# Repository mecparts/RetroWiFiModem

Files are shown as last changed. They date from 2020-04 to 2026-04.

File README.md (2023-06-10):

# Retro WiFi modem

## An ESP8266 based RS232 \<-\> WiFi modem with Hayes AT style commands and LED indicators

### (And yes, this version makes the noises)

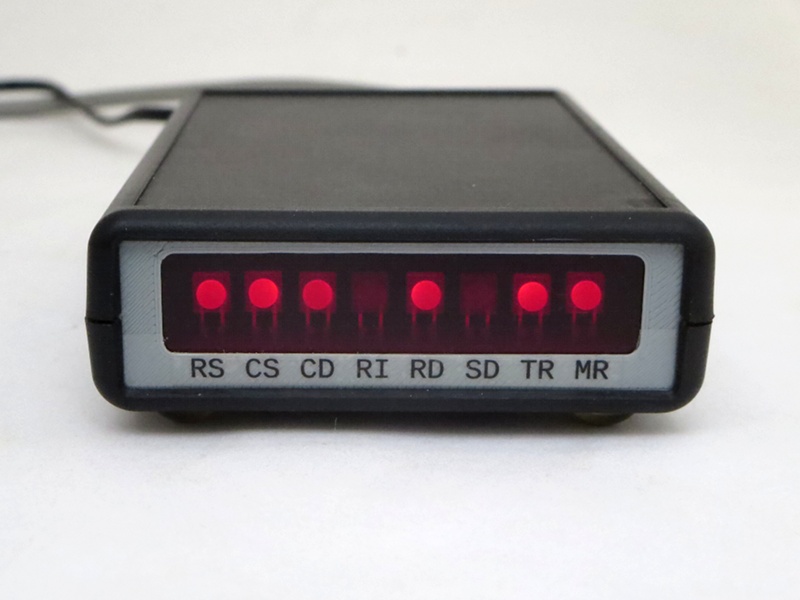
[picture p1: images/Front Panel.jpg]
Front Panel


This project grew out of a desire to get an old Ampro LB+/Z80 hooked up
to the Internet.

Right from the start, I knew I wanted a row of LED indicators at the
front of the modem so that it would be reminiscent of an old Hayes
Smartmodem. (I briefly considered finding an old Smartmodem on eBay, but
soon remembered that the case had in fact been made of metal; they don't
build 'em like that anymore.)

Since the modem was going to be hooked up to the Little Board's
serial port, I needed an actual RS-232 level serial port, with either a
DB-25 or DE-9 connector.

And finally, since I wanted the Hayes style LEDs, I thought it would be
handy to have the Hayes AT commands too, at least as close as I could
manage.

That was all I started with. I couldn't tell you how I stumbled across
the whole WiFi modem thing; I can't even remember what terms I searched
with but very quickly I came across the message thread at [WiFi232's
Evil
Clone](http://www.vcfed.org/forum/entry.php?740-WiFi232-s-Evil-Clone&bt=1056).
Inspired by that, and [Paul Rickards'
WiFi232](http://biosrhythm.com/?page_id=1453), and [Daniel Jameson's
ESP8266 based virtual modem](https://github.com/stardot/esp8266_modem) I
got started.

I had a preliminary version put together and working by the first
evening. Then the wholesale changes to the software began. And for the
longest time, it looked like they'd never end. Eventually though, they
calmed down and "wholesale changes" downshifted to "another tweak I'd
like to make."

The hardware didn't change nearly as much from beginning to end. I did
the development on a Wemos D1 R1 and a little half length solderless
breadboard mounted together. The plan for the final hardware was always
to use a [Wemos D1 mini](https://docs.wemos.cc/en/latest/d1/d1_mini.html).
A MAX3237 took care of the 3.3V <-> RS-232 level shifting, and a
74HCT245 was used to drive the indicator LEDs.

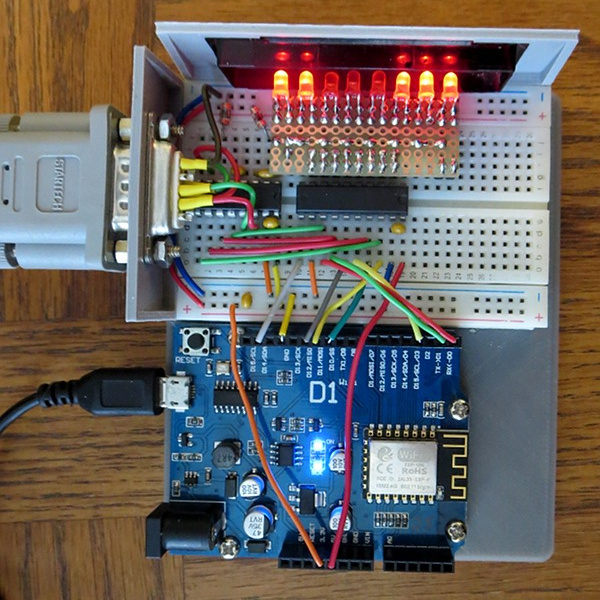
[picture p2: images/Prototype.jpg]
Prototype


The only major additions to the hardware during development was an OR
gate on the serial output from the ESP8266 and the addition of a
DFPlayer Mini for the dialing and connection sounds.

On startup, the ESP8266 sends out some debug information
(at an oddball baud rate) through the serial port. It shows up as
garbage characters to whatever's hooked up to the serial port. It
annoyed me enough that I fed the Tx signal through the OR gate, with the
other input hooked up to an output pin that I could count on remaining
high (thereby masking off the Tx signal) until after the sketch had
started and set it low.

And while it didn't make the cut the first time around, there's a
DFPlayer Mini in this version for faux dialing and connection sounds.
They really do complete the whole retro feel (but they can be turned off
too).

## The Hardware

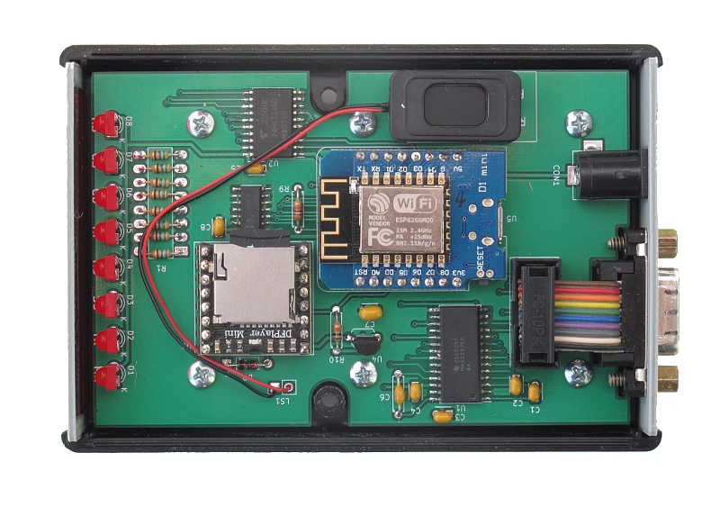
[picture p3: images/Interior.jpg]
Interior


The second time around, I decided that I was going to bite the bullet
and go with some surface mount stuff, starting with the MAX3237. Having
a full suite of RS-232 control signals seemed worth it. I stuck with
through hole components where I could (I already had most of them in my
parts box) but adding the DFPlayer Mini meant that the 74HC32 and
74HCT245 had to be surface mount just to make them fit.

In keeping with the retro theme, the modem uses classic Hayes style
blinking LEDs and a DE-9F for the RS-232 connector. Everything is
displayed and brought out to the DE-9F connector: RTS, CTS, DSR, DTR,
DCD, RI, TxD and RxD.

The PCB is laid out for a
[Wemos D1 mini](https://docs.wemos.cc/en/latest/d1/d1_mini.html) and the
software expects to see just that. If you're just using the software and
not the PCB, there's no reason you couldn't use another kind of ESP8266
board; I used a D1 R1 myself when I was developing the modem. You'd just
need to add pin definitions for your board in RetroWiFiModem.h.

A separate 3.3V regulator is used to power the MAX3232 IC and 74HC32
quad OR gate. Some (most?) D1 mini clones have the smallest 3.3V
regulator on board that they can get away with to power the board, and
they don't have a lot of mA's left over to power anything else. Better
safe than sorry.

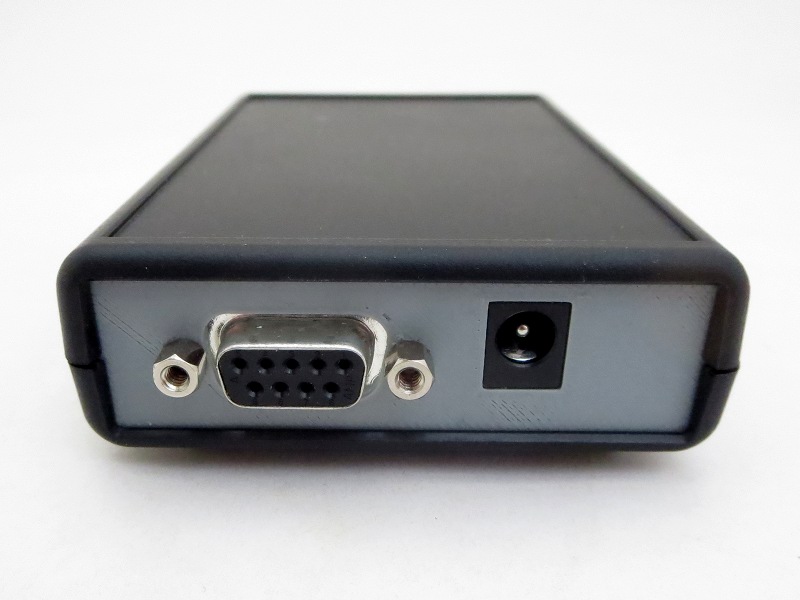
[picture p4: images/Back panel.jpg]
Back Panel


The power connector expects a 2.1mm I.D. x 5.5mm O.D. barrel plug,
delivering 5 volts, centre positive.  I used a Tri-Mag L6R06H-050 (5V,
1.2A), [DigiKey part#
364-1251-ND](https://www.digikey.com/product-detail/en/tri-mag-llc/L6R06H-050/364-1251-ND/7682614).
If you plug in a 9V adapter like you'd use for an Arduino, you *will*
let the magic smoke out and have an ex-modem on your hands.

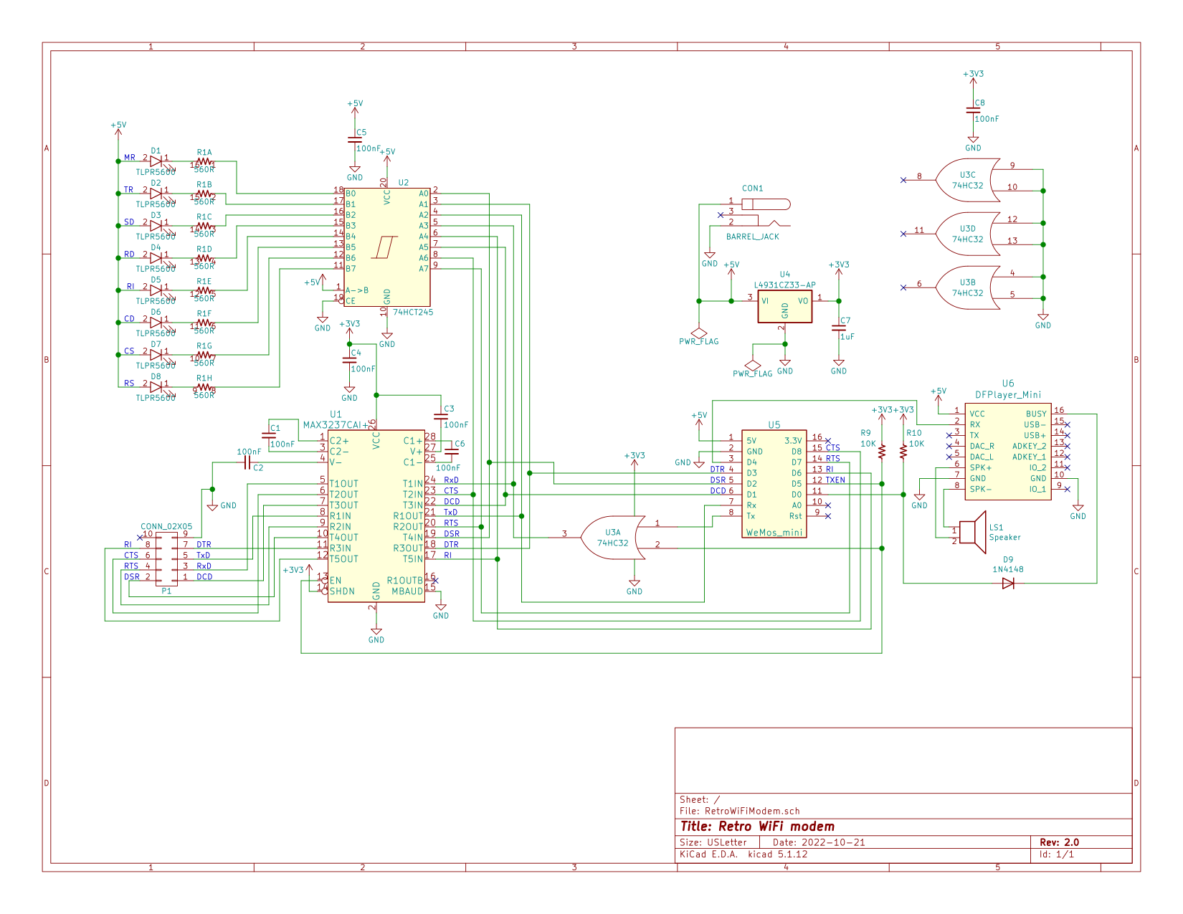
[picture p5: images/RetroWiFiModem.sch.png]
Schematic


On the off chance that there's someone else out there with a well
stocked parts box and a burning desire to put together their own WiFi
modem, there's a [BOM](kicad/RetroWiFiModem-bom.csv) in the kicad
sub directory. If you actually had to go out and buy all the parts, it
really wouldn't be cost effective.

Then again, how practical is getting an Ampro Little Board on the
Internet? Practicality isn't always everything. Sometimes nostalgia is
worth the effort.

## The case

Like I said at the start, I would have loved to have used an old Hayes
Smartmodem case, but they were metal and wouldn't have allowed the WiFi
to work particularly well.

In the end I went with a Hammond 1593N case (DigiKey part #
[HM963-ND](https://www.digikey.com/en/products/detail/hammond-manufacturing/1593NBK/1090774)
or [HM964-ND](https://www.digikey.com/en/products/detail/hammond-manufacturing/1593NGY/1090775)
depending on whether you like black or grey). STL and OpenSCAD
files are included for the front and back panels. You could use the
proper Hammond red panel for the front (DigiKey part #
[HM965-ND](https://www.digikey.com/en/products/detail/hammond-manufacturing/1593NIR10/1090776)),
*but* they're only available in 10 packs and their price is highway robbery.
I ended up using a slightly smaller red panel (DigiKey part #
[HM889-ND](https://www.digikey.com/en/products/detail/hammond-manufacturing/1593SIR10/409899))
that was ~much~ cheaper (it has recently increased in price by 500%)
and available in single units.

The labels are unbelievably low tech. I print them on a piece of inkjet
transparency film. I then cut that down to size so that it will fit
under the LED opening. Then I attach the trimmed down transparency piece
to a length of matte finish, invisible tape and carefully position it in
place. A bit of careful work with an x-acto knife and you've got
yourself a label that looks like it's part of the panel. If you look
closely at the front panel image you can see the edges of the
transparency film and the tape, but in practice they both essentially
disappear.

## The PCB

The PCB includes cutouts for the two columns that join the case
together, and mounting holes for the 6 standoffs. Also, there's an oddly
shaped cutout in back end to allow a particular IDC DE-9F I had on hand.
It's available from DigiKey (or a very close clone is) but it's fairly
pricey. But there's plenty of room for an ordinary solder cup DE-9F.
You'd most likely want to omit the 10 pin header and just wire the DE-9F
right to the board.

## The Software

In a nod to its popularity, the command set I used largely follows that
used in [Paul Rickards' WiFi232](http://biosrhythm.com/?page_id=1453)
modem. Even if the innards are completely different, it made sense to
make it *work* like what people were already used to. There's a reason
everyone's been copying the Hayes command set for almost 40 years!

### First time setup

The default serial configuration is 9600bps, 8 data bits, no parity, 1
stop bit.

Here's the commands you need to set up the modem to automatically
connect to your WiFi network:

1. `AT$SSID=your WiFi network name` to set the WiFi network that the
modem will connect to when it powers up.
2. `AT$PASS=your WiFi network password` to set the password for the
network.
3. `ATC1` to connect to the network.
4. Optional stuff:
   * `AT$SB=speed` to set the default serial speed.
   * `AT$SU=dps` to set the data bits, parity and stop bits.
   * `ATNETn` to select whether or not to use Telnet protocol.
   * `AT&Kn` to use RTS/CTS flow control or not.
   * `AT&Dn` to set up DTR handling.
5. `AT&W` to save the settings.

Once you've done that, the modem will automatically connect to your WiFi
network on power up and will be ready to "dial up" a connection with
ATDT.

### Command Reference

Multiple AT commands can be typed in on a single line. Spaces between
commands are allowed, but not within commands (i.e. AT S0=1 X1 Q0 is
fine; ATS 0=  1 is not). Commands that take a string as an argument
(e.g. AT$SSID=, AT$TTY=) assume that *everything* that follows is a part
of the string, so no commands are allowed after them.

Command | Details
------- | -------
+++     | Online escape code. Once your modem is connected to another device, the only command it recognises is an escape code of a one second pause followed by three typed plus signs and another one second pause, which puts the modem back into local command mode. The character used can be set with `ATS2=n`.
A/      | Repeats the last command entered. Do not type AT or press Enter.
AT      | The attention prefix that precedes all command except A/ and +++.
AT?     | Displays a help cheatsheet.
ATA     | Force the modem to answer an incoming connection when the conditions for auto answer have not been satisfied.
ATC?<br>ATC*n* | Query or change the current WiFi connection status. A result of 0 means that the modem is not connected to WiFi, 1 means the modem is connected. The command ATC0 disconnects the modem from a WiFi connection. ATC1 connects the modem to the WiFi.
ATDS*n* | Calls the host specified in speed dial slot *n* (0-9).
ATDT<i>[+=-]host[:port]</i> | Tries to establish a WiFi TCP connection to the specified host name or IP address. If no port number is given, 23 (Telnet) is assumed. You can also use ATDT to dial one of the speed dial slots in one of two ways:<br><br><ul><li>The alias in each speed dial slot is checked to see if it matches the specified hostname.</li><li>A host specified as 7 identical digits dials the slot indicated by the digit. (i.e. 2222222 would speed dial the host in slot 2).</li></ul>Preceding the host name or IP address with a +, = or - character overrides the ATNET setting for the period of the connection.<br><br><ul><li>**+** forces NET2 (fake Telnet)</li><li>**=** forces NET1 (real Telnet)</li><li>**-** forces NET0 (no Telnet)</li></ul>Once the dial attempt has begun, pressing any key before the connection is established will abort the attempt.
ATE?<br>ATE*n* | Command mode echo. Enables or disables the display of your typed commands.<br><br><ul><li>E0 Command mode echo OFF. Your typing will not appear on the screen.</li><li>E1 Command mode echo ON. Your typing will appear on the screen.</li></ul>
ATGET*http&#58;//host[/page]* | Displays the contents of a website page. **https** connections are not supported. Once the contents have been displayed, the connection will automatically terminate.
ATH | Hangs up (ends) the current connection.
ATI | Displays the current network status, including sketch build date, WiFi and call connection state, SSID name, IP address, and bytes transferred.
ATL?<br>ATL*n* | Query or set the volume of the speaker (0-3).
ATM?<br>ATM*n* | Query or set whether the speaker is enabled or disabled. ATM0 disables the speaker. ATM1 enables it.
ATNET?<br>ATNET*n* | Query or change whether telnet protocol is enabled. A result of 0 means that telnet protocol is disabled; 1 is *Real* telnet protocol and 2 is *Fake* telnet protocol. If you are connecting to a telnet server, it may expect the modem to respond to various telnet commands, such as terminal name (set with `AT$TTY`), terminal window size (set with `AT$TTS`) or terminal speed. Telnet protocol should be enabled for these sites, or you will at best see occasional garbage characters on your screen, or at worst the connection may fail.<br><br>The difference between *real* and *fake* telnet protocol is this: with *real* telnet protocol, a carriage return (CR) character being sent from the modem to the telnet server always has a NUL character added after it. The implementation of the telnet protocol used by some BBSes doesn't properly strip out the NUL character. When connecting to such BBSes (Particles! is one), use *fake* telnet.<br><br>When using *real* telnet protocol, when the telnet server sends a CR character followed by a NUL character, only the CR character will be sent to the serial port; the NUL character will be silently stripped out. With *fake* telnet protocol, the NUL will be passed through.
ATO | Return online. Use with the escape code (+++) to toggle between command and online modes.
ATQ?<br>ATQ*n* | Enable or disable the display of result codes. The default is Q0.<br><br><ul><li>Q0 Display result codes.</li><li>Q1 Suppress result codes (quiet).</li></ul>
ATRD<br>ATRT | Displays the current UTC date and time from NIST in the format *YY-MM-DD HH:MM:SS*. A WiFi connection is required and you cannot be connected to another site.
ATS0?<br>ATS0=*n* | Display or set the number of "rings" before answering an incoming connection. Setting `S0=0` means "don't answer".
ATS2?<br>ATS2=*n* | Display or set the ASCII code used in the online escape sequence. The default value is 43 (the + plus character). Setting it to any value between 128 and 255 will disable the online escape function.
ATV?<br>ATV*n* | Display result codes in words or numbers. The default is V1.<br><br><ul><li>V0 Display result codes in numeric form.</li><li>V1 Display result codes in text form.</li></ul>
ATX?<br>ATX*n* | Control the amount of information displayed in the result codes. The default is X1 (extended codes).<br><br><ul><li>X0 Display basic codes (CONNECT, NO CARRIER)</li><li>X1 Display extended codes (CONNECT speed, NO CARRIER (connect time))</li></ul>
ATZ | Resets the modem.
AT&F | Reset the NVRAM contents and current settings to the sketch defaults. All settings, including SSID name, password and speed dial slots are affected.
AT&D?<br>AT&D*n* | Display or set the handling of DTR going inactive. The default is &D0 (ignored).<br><br><ul><li>&D0 Ignore</li><li>&D1 Go to command mode</li><li>&D2 End call</li><li>&D3 Reset modem</li></ul>
AT&K?<br>AT&K*n* | Data flow control. Prevents the modem's buffers for received and transmitted from overflowing.<br><br><ul><li>&K0 Disable data flow control.</li><li>&K1 Use hardware flow control. Requires that your computer and software support Clear to Send (CTS) and Request to Send (RTS) at the RS-232 interface.</li></ul>
AT&R?<br>AT&R=*server pwd* | Query or change the password for incoming connections. If set, the user has 3 chances in 60 seconds to enter the correct password or the modem will end the connection.
AT&V*n* | Display current or stored settings.<br><br><ul><li>&V0 Display current settings.</li><li>&V1 Display stored settings.</li></ul>
AT&W | Save current settings to NVRAM.
AT&Zn?<br>AT&Z*n*=*host[:port],alias* | Store up to 10 numbers in NVRAM, where *n* is the position 0-9 in NVRAM, and *host[:port]* is the host string, and *alias* is the speed dial alias name. The host string may be up to 50 characters long, and the alias string may be up to 16 characters long.<br><br>Example: `AT&Z2=particlesbbs.dyndns.org:6400,particles`<br><br>This number can then be dialed in any of the following ways:<br><br><ul><li>`ATDS2`</li><li>`ATDTparticles`</li><li>`ATDT2222222`</li></ul>
AT$AE?<br>AT$AE=*startup AT cmd* | Query or change the command line to be executed when the modem starts up.
AT$AYT | Sends a Telnet "Are You There?" command if connected to a Telnet remote.
AT$BM?<br>AT$BM=*server busy msg* | Query or change a message to be returned to an incoming connection if the modem is busy (i.e. already has a connection established).
AT$MDNS<br>AT$MDNS=*mDNS name* | Query or change the mDNS network name (defaults to "espmodem"). When a non zero TCP port is defined, you can telnet to that port with **telnet mdnsname.local port**.
AT$PASS?<br>AT$PASS=*WiFi pwd* | Query or change the current WiFi password. The password is case sensitive. Clear the password by issuing the set command with no password. The maximum length of the password is 64 characters.
AT$SB?<br>AT$SB=*n* | Query or change the current baud rate. Valid values for "n" are 110, 300, 450, 600, 710, 1200, 2400, 4800, 9600, 19200, 38400, 57600, 76800 and 115200. Any other value will return an ERROR message. The default baud rate is 1200. The Retro WiFi modem does not automatically detect baud rate like a dial-up modem. The baud rate setting must match that of your terminal to operate properly. It will display garbage in your terminal otherwise.
AT$SP?<br>AT$SP=*n* | TCP server port to listen on. A value of 0 means that the TCP server is disabled, and no incoming connections are allowed.
AT$SSID?<br>AT$SSID=*ssid name* | Query or change the current SSID to the specified name. The given SSID name is case sensitive. Clear the SSID by issuing the set command with no SSID. The maximum length of the SSID name is 32 characters.
AT$SU?<br>AT$SU=*dps* | Query or change the current number of data bits ('d'), parity ('p') and stop bits ('s") of the serial UART. Valid values for 'd' are 5, 6, 7 or 8 bits. Valid values for 'p' are (N)one, (O)dd or (E)ven parity. Valid values for 's' are 1 or 2 bits. The default settings are 8N1. The UART setting must match your terminal to work properly.
AT$TTL?<br>AT$TTL=*telnet location* | Query or change the Telnet location value to be returned when the Telnet server issues a SEND-LOCATION request. The default value is "Computer Room".
AT$TTS?<br>AT$TTS=*WxH* | Query or change the window size (columns x rows) to be returned when the Telnet server issues a NAWS (Negotiate About Window Size) request. The default value is 80x24. For terminals that are smaller than 80x24, setting these values appropriately will enable paging on the help (AT?) and network status (ATI) commands.
AT$TTY?<br>AT$TTY=*terminal type* | Query or change the terminal type to be returned when the Telnet server issues a TERMINAL-TYPE request. The default value is "ansi".
AT$W?<br>AT$W=*n* | Startup wait.<br><br><ul><li>$W=0 Startup with no wait.</li><li>$W=1 Wait for the return key to be pressed at startup.</li></ul>

### Updating the Software

While I liked the idea of being able to update the software OTA, it
seemed to make more sense in my situation to be able to *push* a new
version as I built it rather than have the modem *pull* it. So that's
what I did. It uses the default OTA upload capability built into the
Arduino IDE.

**Jan 24/22:** It's been reported that the ESP8266 core is slightly
snafu'd at the moment, and that it's breaking things in the modem
software. As a workaround, I've added the bin file that gets uploaded
to the modem in the repository. I haven't updated my ESP8266 core in
ages; "if it isn't broken, don't break it", and everything still works
for me. The bin file can be uploaded with the *espota.py* tool in the
ESP8266 tool directory tree.

(If TPTB have deleted/renamed/moved that tool in the current core,
you'll have to figure out how to do a manual OTA update.)

### RTS/CTS handshaking and a dead spin loop issue

Something I noticed with ESP8266 software that puzzled me was the
number of places I saw a series of Serial print statements being broken
up with calls to yield(), like so:

```
   Serial.print("Hello world!\n");
   yield();
   Serial.print("How are you today?\n");
   yield();
```
It didn't take long to figure out what was going on; The print() call
was blocking, and at lower baud rates, even printing a few relatively
short strings was enough to cause the watchdog to bark and cause a
reset. So the repetitive yield() calls were an attempt to feed the
watchdog often enough to keep it from barking.

What does this have to do with RTS/CTS handshaking? Simply put,
lowering RTS for more than a few seconds was causing the watchdog to
bark as well. So I started digging.

In cores/esp8266/uart.cpp I found the following function:

```
static void
uart_do_write_char(const int uart_nr, char c)
{
    while(uart_tx_fifo_full(uart_nr));

    USF(uart_nr) = c;
}
```

This is the low level function that everything calls to send a character
out the serial port. The cause of the watchdog barking is in the dead
spin while loop. It waits until there's room in the transmit FIFO to add
another character. So if RTS/CTS handshaking is enabled, and RTS is low
for longer than the watchdog likes: woof.

What I did to quiet the watchdog down both when sending long strings at
low baud rates and during long waits for RTS to come active again was to
add a yield() call to the dead spin while loop, like so:

```
static void
uart_do_write_char(const int uart_nr, char c)
{
    while(uart_tx_fifo_full(uart_nr))
      yield();

    USF(uart_nr) = c;
}
```

This way, no matter how long the code has to wait for space in the
transmit FIFO, the watchdog is kept well fed and quiet.

## Status

As I said way back in 2020, is a personal project like this ever
*really* finished? I've had two units assembled and in use since the
spring of 2020, and a third since 2022, and while there's
been some software changes since then, and a second rev of the hardware
to bring out all the RS-232 control signals and add in the faux dialing
and connections sounds, I really don't expect any more changes. But I've
said that before! There are no outstanding bugs that I'm aware of, and
no new features on my wish list. For the time being at least, I think
it's complete.

### Linux, Telnet, Zmodem and downloading binary files

Have you used the modem to 'dial' into a Linux box? And have you done a
`sz binary_file` on the Linux box? And at a completely reproducible
point in the file, has the connection dropped? But other binary files
work just fine? Then read on.

This drove me slightly batty for months. I finally narrowed it down to
trying to send blocks of binary data with a large number of FF bytes. I
eventually created a test file consisting of 2K of FF and used that to
test with. I could download it through the modem with Xmodem just fine.
Ymodem also worked if I kept the block size down to 128 bytes - but the
connection would drop instantly if I tried sending 1K blocks. Same thing
with Zmodem.

In fact, if I just tried `cat binary_file`, the connection would
drop. Which eventually got me thinking. Sitting at the console on my
main Linux box, I telnet'd to the same box and logged in. No WiFi modem
involved anywhere, just a telnet session on the console to the same box.
I then did a `cat binary_file`. The telnet connection dropped, and I
was back in my original session.

It's the Linux telnet daemon. Not the modem at all.

To prove it to myself, I hooked up WiFi modems to two systems on their
serial ports and had one dial into the other. I could send the all FF
binary file back and forth with Zmodem and Ymodem, no trouble at all.

But you really, really need to download that binary file through the
modem from a telnet connection to a Linux box? You're not going to be
able to use Zmodem. Ymodem will work (the sy command defaults to 128
byte blocks), as will Xmodem. But not Zmodem.

Oddly enough, the telnet daemon has no trouble *receiving* the all FF
binary file. Only sending it. Your guess as to why is probably better
than mine.

## References

* [WiFi232 - An Internet Hayes Modem for your Retro Computer](http://biosrhythm.com/?page_id=1453)<br>
* [WiFi232's Evil Clone](https://forum.vcfed.org/index.php?threads/wifi232s-evil-clone.1070412/)<br>
* [Jussi Salin's Virtual modem for ESP8266](https://github.com/jsalin/esp8266_modem)<br>
* [Stardot's ESP8266 based virtual modem](https://github.com/stardot/esp8266_modem)<br>
* [Roland Juno's ESP8266 based virtual modem](https://github.com/RolandJuno/esp8266_modem)

## Acknowledgements

* A whole lot of people owe a big vote of thanks to Jussi Salin for
releasing their virtual modem code for the ESP8266 and starting the
ball rolling.
* Paul Rickards for an amazing bit of hardware to draw inspiration from.
* All the Stardot contributors for their work.
* And, of course, Dennis C. Hayes for creating something so simple and
elegant that has stood the test of time.

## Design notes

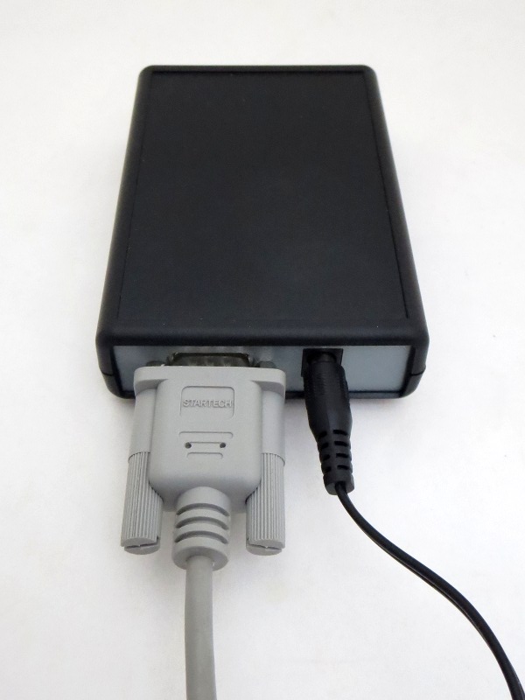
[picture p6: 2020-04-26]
images/Plugged in.jpg

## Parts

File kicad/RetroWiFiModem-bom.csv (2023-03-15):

Reference | Quantity | Value | DigiKey PN | BC-Robotics PN
P1 | 1 | CONN_02X05 | ED1543-ND
U3 | 1 | SN74HC32DR | 296-1199-1-ND
U4 | 1 | L4931CZ33-AP | LP2950ACZ-3.3GOS-ND
D3-D8 | 8 | TLPR5600 | TLPR5600-ND
C1-C2,C4-C6,C8 | 6 | 100nF | 399-9859-1-ND
C7 | 1 | 1uF | 399-3529-ND
CON1 | 1 | BARREL_JACK | 839-54-00166-ND
R1 | 8 | 560R | CF18JT560RCT-ND
R9-R10 | 2 | 10K | CF18JT10K0CT-ND
U1 | 1 | MAX3237ECDWR | 296-36945-1-ND
U2 | 1 | 74HCT245D | 74HCT245DCT-ND
C3 | 1 | 100nF | 399-9859-1-ND
U5 | 1 | WeMos_mini
U6 | 1 | DFPlayer_Mini | 1738-1041-ND
LS1 | 1 | Speaker |  | AUD-013
D9 | 1 | 1N4148 | 1N4148FS-ND
 | 1 | Hammond 1593NBK case | HM963-ND
 | 1 | Hammond red panel | HM889-ND
 | 50 | PCB screws | HM1442-ND
 | 1 | 5V wall adapter | 364-1251-ND
 | 1 | DE-9F IDC connector | 5746861-4-ND
 | 2 | 4-40 hex standoffs | A104867-ND
 | 4 | 8 pos machine pin socket | 2057-SMC-1-08-1-GT-ND
 | 1 | 10 pos IDC socket | 1175-1443-ND
 | 1 | 10 cond ribbon cable | 3M157815-1-ND

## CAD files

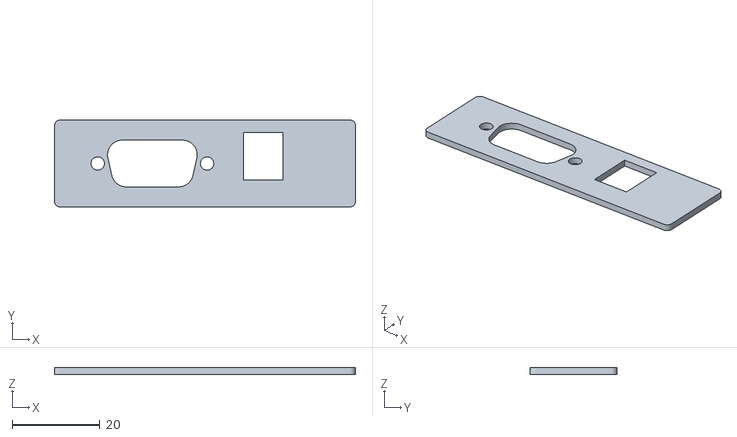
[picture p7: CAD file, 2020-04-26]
case/back_panel.stl
68.8 x 19.8 x 1.50

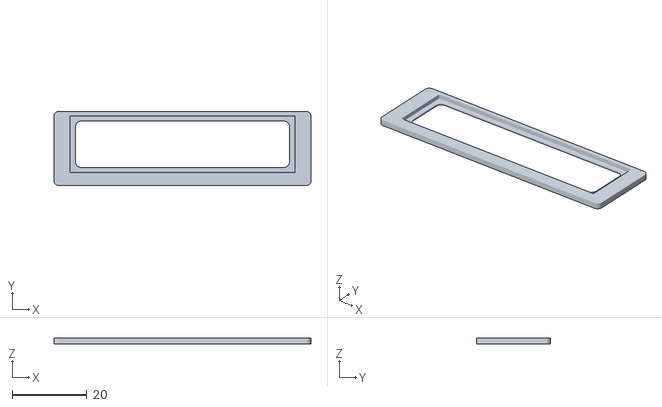
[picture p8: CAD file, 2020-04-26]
case/front_panel.stl
68.8 x 19.8 x 1.50

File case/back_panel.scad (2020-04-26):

$fn=64;
eps = 0.04;
inch = 25.4;

panel_x = 68.76;
panel_y = 19.84;
panel_z = 1.5;
panel_r = 0.05 * inch;

barrel_x = 0.354*inch;
barrel_y = 0.428*inch;

module dsub(c,e,a)
{
   r=3.35;
   h=3.96;
   md=3.05;
   hull() {
      translate([-c/2,h/2,0])
         circle(r=r);
      translate([c/2,h/2,0])
         circle(r=r);
      translate([-e/2,-h/2,0])
         circle(r=r);
      translate([e/2,-h/2,0])
         circle(r=r);
   }
   translate([-a/2,0,0])
      circle(d=md);
   translate([a/2,0,0])
      circle(d=md);
}

module dsub9() {
   dsub(c=13.77,e=12.01,a=24.99);
}

difference() {
   linear_extrude(height=panel_z) {
      hull() {
         translate([panel_r, panel_r, 0]) {
            circle(r=panel_r);
         }
         translate([panel_x-panel_r, panel_r, 0]) {
            circle(r=panel_r);
         }
         translate([panel_x-panel_r, panel_y-panel_r, 0]) {
            circle(r=panel_r);
         }
         translate([panel_r, panel_y-panel_r, 0]) {
            circle(r=panel_r);
         }
      }
   }
   translate([panel_x/2 - 12.015, panel_y/2, -eps] ) {
      linear_extrude(height=panel_z+2*eps) {
         dsub9();
      }
   }
   translate([panel_x/2+13.33,6.17+barrel_y/2,-eps]) {
      linear_extrude(height=panel_z+2*eps) {
         square([barrel_x, barrel_y],center=true);
      }
   }
}

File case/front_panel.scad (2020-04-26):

$fn=64;
eps = 0.04;
inch = 25.4;

panel_x = 68.76;
panel_y = 19.84;
panel_z = 1.5;
panel_r = 0.05 * inch;

lens_x = 2.363 * inch;
lens_y = 0.592 * inch;
lens_z = 0.062 * inch;

bezel_x = 2.258 * inch;
bezel_y = 0.487 * inch;
bezel_r = 1/16 * inch;

difference() {
   linear_extrude(height=panel_z) {
      hull() {
         translate([panel_r, panel_r, 0]) {
            circle(r=panel_r);
         }
         translate([panel_x-panel_r, panel_r, 0]) {
            circle(r=panel_r);
         }
         translate([panel_x-panel_r, panel_y-panel_r, 0]) {
            circle(r=panel_r);
         }
         translate([panel_r, panel_y-panel_r, 0]) {
            circle(r=panel_r);
         }
      }
   }
   translate([panel_x/2,panel_y-1.27-lens_y/2,0.4]) {
      linear_extrude(height=panel_z+2*eps) {
         square([lens_x+2*eps, lens_y+2*eps],center=true);
      }
   }
   translate([panel_x/2,panel_y-1.27-lens_y/2,-eps]) {
      linear_extrude(height=panel_z+2*eps) {
         hull() {
            translate([-bezel_x/2+bezel_r, -bezel_y/2+bezel_r, 0]) {
               circle(r=bezel_r);
            }
            translate([bezel_x/2-bezel_r, -bezel_y/2+bezel_r, 0]) {
               circle(r=bezel_r);
            }
            translate([bezel_x/2-bezel_r, bezel_y/2-bezel_r, 0]) {
               circle(r=bezel_r);
            }
            translate([-bezel_x/2+bezel_r, bezel_y/2-bezel_r, 0]) {
               circle(r=bezel_r);
            }
         }
      }
   }
}

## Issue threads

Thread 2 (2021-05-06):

use with ESP 12e module.

Biker1bob, 2021-05-06:
Wanted to ask, but I cannot find any way to contact you. I could use your firmware with an ESP 12e module by making sure the pin out is correct?
When I try and use your code in Adruino IDE it says there is a missing ESP_EEPROM.h .. now I have done this with a FLASHER and .bin but not with the IDE .. is that something it finds once I choose the board?
Sorry for using the issues page.. but could not contact you otherwise.

mecparts, 2021-05-06:
I can't think of any reason off the top of my head why you couldn't make a bare ESP12e module work with the firmware.

As for the missing ESP_EEPROM.h... did you install the library?

Biker1bob, 2021-05-06:
NodeMCU V3 Lua ESP8266 is the exact module, so I have the pinouts right there. I have programmed Zimodem. but its setup for a C64.. you have made specific changes for RS232. I would like to try and run the LEDs off the signal pins - to a resistor and then to LEDS in a old plastic modem case I have. Should work I think.

Biker1bob, 2021-05-06:
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

mecparts, 2021-05-06:
A NodeMCU board? I don't imagine you'll have many problems with that. Just check how the pins are mapped and add the mappings to RetroWifiModem.h. It wouldn't surprise me if they're exactly the same as the D1 Mini; the original D1 was the odd duck as I recall.

Biker1bob, 2021-05-06:
Do I need to change the name in the file  #include NodeMCU?  In order to compile and test do I need the board plugged in?

Not getting far with Arduno IDE

James

mecparts, 2021-05-07:
No, as it says in the readme, and as I said in an earlier message, all you should have to do is to add the correct pin mapping for your board in the RetroWifiModem.h file.

Biker1bob, 2021-05-07:
guess I am not getting it.. I dont know how to get it to accept the .h files it cannot find.

mecparts, 2021-05-07:
Your issues seem to be with the IDE rather than the firmware, but... I imagine you haven't installed the libraries you need. If this is your first time using the Arduino IDE, perhaps you'd do better starting with a simpler example to get your feet wet, and then working your way up.

Biker1bob, 2021-05-07:
Thanks for your project I'll see what I can figure out.

DRF-Solutions, 2021-06-17:
@Biker1bob Did you manage to get this working? I too am using the same board as you and ran into the same issue.
I managed to get libraries installed, and now get errors at compile stating the below.
I did also try changing the #ifdef ARDUINO_ESP8266_NODEMCU, to no avail...

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

DRF-Solutions, 2021-06-18:
I think the issue is a certain library has been used, but the exact library used hasn't been mentioned or documented anywhere - making this project useless to anyone who doesn't already have that library installed.

@mecparts, can you please advise which libraries you have installed that are supporting this project?

Thanks

mecparts, 2021-06-18:
I would have thought that the #includes <...> in the main sketch file would have made the libraries used pretty clear. And the only library used that isn't included with the standard ESP8266 install is ESP_EEPROM. Which has nothing to do with defining the I/O pins, by the way. As stated in the README file:

> If you're just using the software and not the PCB, there's no reason you couldn't use another kind of ESP8266 board; I used a D1 R1 myself when I was developing the modem. You'd just need to **add pin definitions for your board in RetroWiFiModem.h**.

Biker1bob, 2021-06-18:
> @Biker1bob Did you manage to get this working? I too am using the same board as you and ran into the same issue.

No I have no luck using Arduino IDE or other programmers. I was able to get zimodem in a .bin which uploaded fine. I have been using my esp8266 wimodem for a month now.

Good luck.

Closed 2021-05-07.

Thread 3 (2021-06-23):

Question about PCB and front panel labels

sofakng, 2021-06-23:
This is a fantastic project and I absolutely love the design!

Do you have the gerber files so I can order a PCB?

Also, how did you make the front panel piece with the signal labels?

mecparts, 2021-06-24:
I'm glad to hear you like my little pandemic project. I've built (and use daily) two of them and am even thinking of putting together a third for another retro computer I'm bringing back to life.

As a pandemic project (i.e. "build it on the cheap with what I have on hand as much as possible") I went low tech on the PCB construction, so I never made Gerber files. Printed off the design on a sheet of that blue 'Press-n-Peel' transfer film, ironed it onto some copper clad board, etched it in an ammonium persulfate solution out on the deck on a hot summer day, drilled and trimmed it. As I said, low tech. But all done with stuff that I had from projects long ago.

Though... I see there's a place offering free PCBs up to 100mm x 150mm now. Maybe I should think about making some Gerbers and getting some boards made. I'd know then if the Gerbers were actually right and could put them up. It's worth looking into (I have visions of the "free" PCBs coming with a 50 buck customs clearing charge from the courier!).

If you look closely at the front panel picture, you can see a change in texture on the 3D printed panel just below the midline of the case. That's a piece of scotch tape, which is holding a piece of transparency film. I picked a font that looked good to me, used a table to get the spacing even, printed the letters on the film, cut it down to size and taped it on. Once again, low tech, cheap, but it works!

sofakng, 2021-06-25:
Thanks so much for the reply!  I've actually purchased a used Hayes 1200 modem to use for this project but then I also forgot about the metal body and wireless signal.

What is the place offering free PCBs?  I've ordered from JLCPCB and it's extremely cheap, but the shipping is expensive.

If you decide to create some gerbers I'd love to give them a try and thanks again for all the information!

mecparts, 2021-06-27:
It's called ALLPCB. I've only taken the briefest of looks at it; I've just got too many balls in the air right now. If it does turn out that it's really free I know I won't be able to stop myself from sitting down, figuring out the gerbers and getting some boards made to check if I've done them right.

sofakng, 2021-06-28:
That's really interesting.  It sells one coupon per month per user for the free PCB and free shipping.

One last question ... what is the purpose of the 74HCT245 and 74HC32 chips?  I see they connect to the LEDs?

mecparts, 2021-06-28:
The side facing LEDs are older items and need a fair bit more current than today's LEDs. The 245 was put in to supply that current w/o overtaxing the 8266s outputs (and why a 245 transceiver rather than say a 244 buffer? I had them on hand). As for the 32 quad OR gate, I'll just let the README speak for itself:

> The only major addition to the hardware during development was an OR gate on the serial output from the ESP8266. On startup, the ESP8266 sends out some debug information (at an oddball baud rate) through the serial port. It shows up as garbage characters to whatever's hooked up to the serial port. It annoyed me enough that I fed the Tx signal through the OR gate, with the other input hooked up to an output pin that I could count on remaining high (thereby masking off the Tx signal) until after the sketch had started and set it low.

sofakng, 2021-07-02:
Thanks again so much for the help!

Closed 2021-07-02.

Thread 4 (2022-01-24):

AT$AE no longer works & mDNS not broadcasting

SanguineBrah, 2022-01-24:
First, thanks for publishing this project. I had a ton of fun putting it together.

I have three modems built - the first was flashed in May of 2021 and the other two in August. It seems that the two more recent modems are showing issues that the earlier one does not:

- The auto exec function seems to be broken. No matter what it is set to, the modem always returns ERROR on power on/ATZ.
- They connect to wifi okay, can be pinged by using their IP address, however they do not broadcast on mDNS and do not show up in the Arduino IDE. I have confirmed this using Bonjour Browser, which shows several broadcasts from my media server but nothing from the modem. The modem from May shows up as it should however.

I've also desoldered and reflashed one of the newer modems with a build that was compiled today and can confirm that both issues are still showing.

Since the code hasn't really changed very much, I feel like this must be a problem with the libraries.

mecparts, 2022-01-24:
A cursory look at open issues in the ESP8266 core reveals that TPTB apparently [broke something in mDNS](https://github.com/esp8266/Arduino/issues/8344) last year and that they're going to look at it in their next sprint - whenever that is. The ESP8266 core being slightly snafu'd isn't something I can do much about. I haven't updated my core in ages, on the "if it isn't broken, don't break it" principle. AT$AE still works fine for me, as does mDNS as you can see below.

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

All I can think of to do from my end is to add the bin file that gets uploaded to the repository. You'll have to work out on your own how to manually upload that; in my ancient core there's a Python program called *espota.py* in the esp8266/tools directory tree that does the job. I make no assumptions that they haven't deleted/renamed/moved it in the current core.

SanguineBrah, 2022-01-24:
Thanks, a working bin will at least get me up and running again until the issue is resolved. Unfortunately, I tried espota.py already following advice in [this thread](https://forum.arduino.cc/t/ota_mode-no-network-port-is-shown/552931/42) and didn't have much luck but I have a desoldering station so it won't be too traumatising to pull the module again and reflash by usb.

SanguineBrah, 2022-01-24:
I can confirm that rolling back to ESP8266 core 2.7.4 and compiling again fixes both of the issues listed above.

mecparts, 2022-01-25:
That's excellent news. It's not excellent that the core is slightly borked, but you know what I mean. I'll close this one out now.

Closed 2022-01-25.

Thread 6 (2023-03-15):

Prevent Telnet server from attempting to enable (unsupported) compression

benryves, 2023-03-15:
I've been having a lot of fun with this project, so thank you for putting it together!

One issue I encountered was a large amount of binary data being dumped to the console when connecting to the [Discworld MUD](http://discworld.imaginary.com/lpc/index.html), i.e. after `atdt discworld.imaginary.com`.

It looks like the MUD attempts to enable [the `COMPRESS2` option](https://www.gammon.com.au/mccp/protocol.html) which the default implementation accepts but doesn't support, hence the garbled binary content instead of the plain text.

I've attached a patch which explicitly blocks attempts to use the `COMPRESS` or `COMPRESS2` options: [dont-compress.patch](https://github.com/mecparts/RetroWiFiModem/files/10985160/dont-compress.patch)

There are still issues connecting to this particular MUD but at least blocking the compression options means you have a better chance of reading what's going on. Thank you again!

mecparts, 2023-03-16:
You can probably imagine my confusion upon first reading... COMPRESS2? I don't recognise that Telnet option... oh, it's a MUD _extension_ to Telnet!

I tried replying DONT to COMPRESS, COMPRESS2 and COMPRESS3 and it's better but still not great. There's still a great glob of text that appears after the first "Your choice: " prompt.

I turned on Telnet option display and there's about another handful of extension options that the server is sending. Replying DONT to all of those got rid of the glob of text but there's still one more gotcha. The server seems to want the client end to be in LINEMODE. That's quite literally a first for anything I've connected to (which, admittedly, consists mostly of Telnet BBSes and actual Linux Telnet servers). So there's no support whatsoever for LINEMODE in the code. Zero. And the server doesn't appear to take DONT for an answer either, at least at first blush. So there's no echo of what you type, which I could see being a problem.

Let me ponder this for a bit and see if I can't figure out how to get the server to work in DONT LINEMODE mode.

benryves, 2023-03-16:
Thank you and sorry to open this particular can of worms, in that case!

The `LINEMODE` issue is one I'd been pondering too. If local echo was sufficient then there is the [VT102](https://vt100.net/docs/vt102-ug/chapter5.html#S5.5.2.13)/[ANSI](https://mdfs.net/Docs/Comp/Comms/ANSICodes) sequence `"\x1B[12l"` to enable local echo and `"\x1B[12h"` to disable it which may be an option if `AT$TTY` was set appropriately (rather than attempting to spoof it in the modem code).

mecparts, 2023-03-20:
Yeah... it's a can of worms all right.
Your MUD server ignored everything I threw at it to get it to go into character mode. Literally ignored. It didn't even reply with DONTs.
I've pushed a commit to DONT all the MUD server's telopt requests. But as for linemode, feel free to fork the code and have at it for yourself. It's just such a niche case that it's not worth pursuing it any further for me.

Closed 2023-03-20.

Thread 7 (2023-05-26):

Difference in v1 and v2 of the project?

sofakng, 2023-05-26:
This project looks absolutely fantastic!

I'm thinking about ordering a PCB and building one but I noticed you have an initial commit for a new version(?).

Has the PCB changed between the versions?  (do you have an extra PCB I can buy from you if you live in the US?)

Thanks!

mecparts, 2023-05-26:
v2 went with surface mount ICs, changed from a MAX3232 to a 3237 to get the full suite of RS232 signals, and added the DFPlayer module. So, yes, the v2 PCB is different than the v1. I only ever made a couple of v1 boards, and those were by hand (iron on toner, ammonium persulfate etchant, drill with a Dremel, the whole 80s experience).

Unfortunately, I'm on the other side of the 49th parallel from the US. Believe it or not, it'd be cheaper ordering your own set of boards from JLCPCB (<$10 Cdn if you choose the cheap shipping, and it's still very quick to arrive) than it would be to try mailing one from Canada to the US.

sofakng, 2023-05-26:
Oh, OK - No problem!

Is the BOM current from the kicad folder?

mecparts, 2023-05-26:
It ought to be. There were no part changes between when it was generated and the gerbers were made, only a footprint adjustment on the DFplayer (I didn't double check a 3rd party footprint and of course it bit me!).

sofakng, 2023-05-26:
Sounds good.  Thanks for such a great project!

mecparts, 2023-05-26:
Enjoy!

Closed 2023-05-26.

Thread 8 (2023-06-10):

How did you print the carrier signals on the front panel?

sofakng, 2023-06-10:
Thanks for such a great project!  I've ordered the PCB and I'm about to order the parts but I have a question.

How did you print the carrier signal labels (RS, CS, CD, etc) on the gray piece?

Also, if you live in the USA, do you have a single piece of that red screen I could purchase?  Digikey and Mouser are sold out.  :(

mecparts, 2023-06-10:
The labels are unbelievably low tech. I print them on a piece of inkjet transparency film. I then cut that down to size so that it will fit under the LED opening. Then I attach the trimmed down transparency piece to a length of matte finish, invisible tape and carefully position it in place. A bit of careful work with an x-acto knife and you've got yourself a label that looks like it's part of the panel. If you look closely at the front panel image you can see the edges of the transparency film and the tape, but in practice they both essentially disappear.

I really ought to add that to the readme.

The red filter is out of stock? Yes, I see that it is. And I see that its price has increased by 500%. Ouch! Unfortunately I'm not in the US. DigiKey claims they'll be back in stock in a week; if they're accurate, that's probably your best bet.

Closed 2023-06-11.

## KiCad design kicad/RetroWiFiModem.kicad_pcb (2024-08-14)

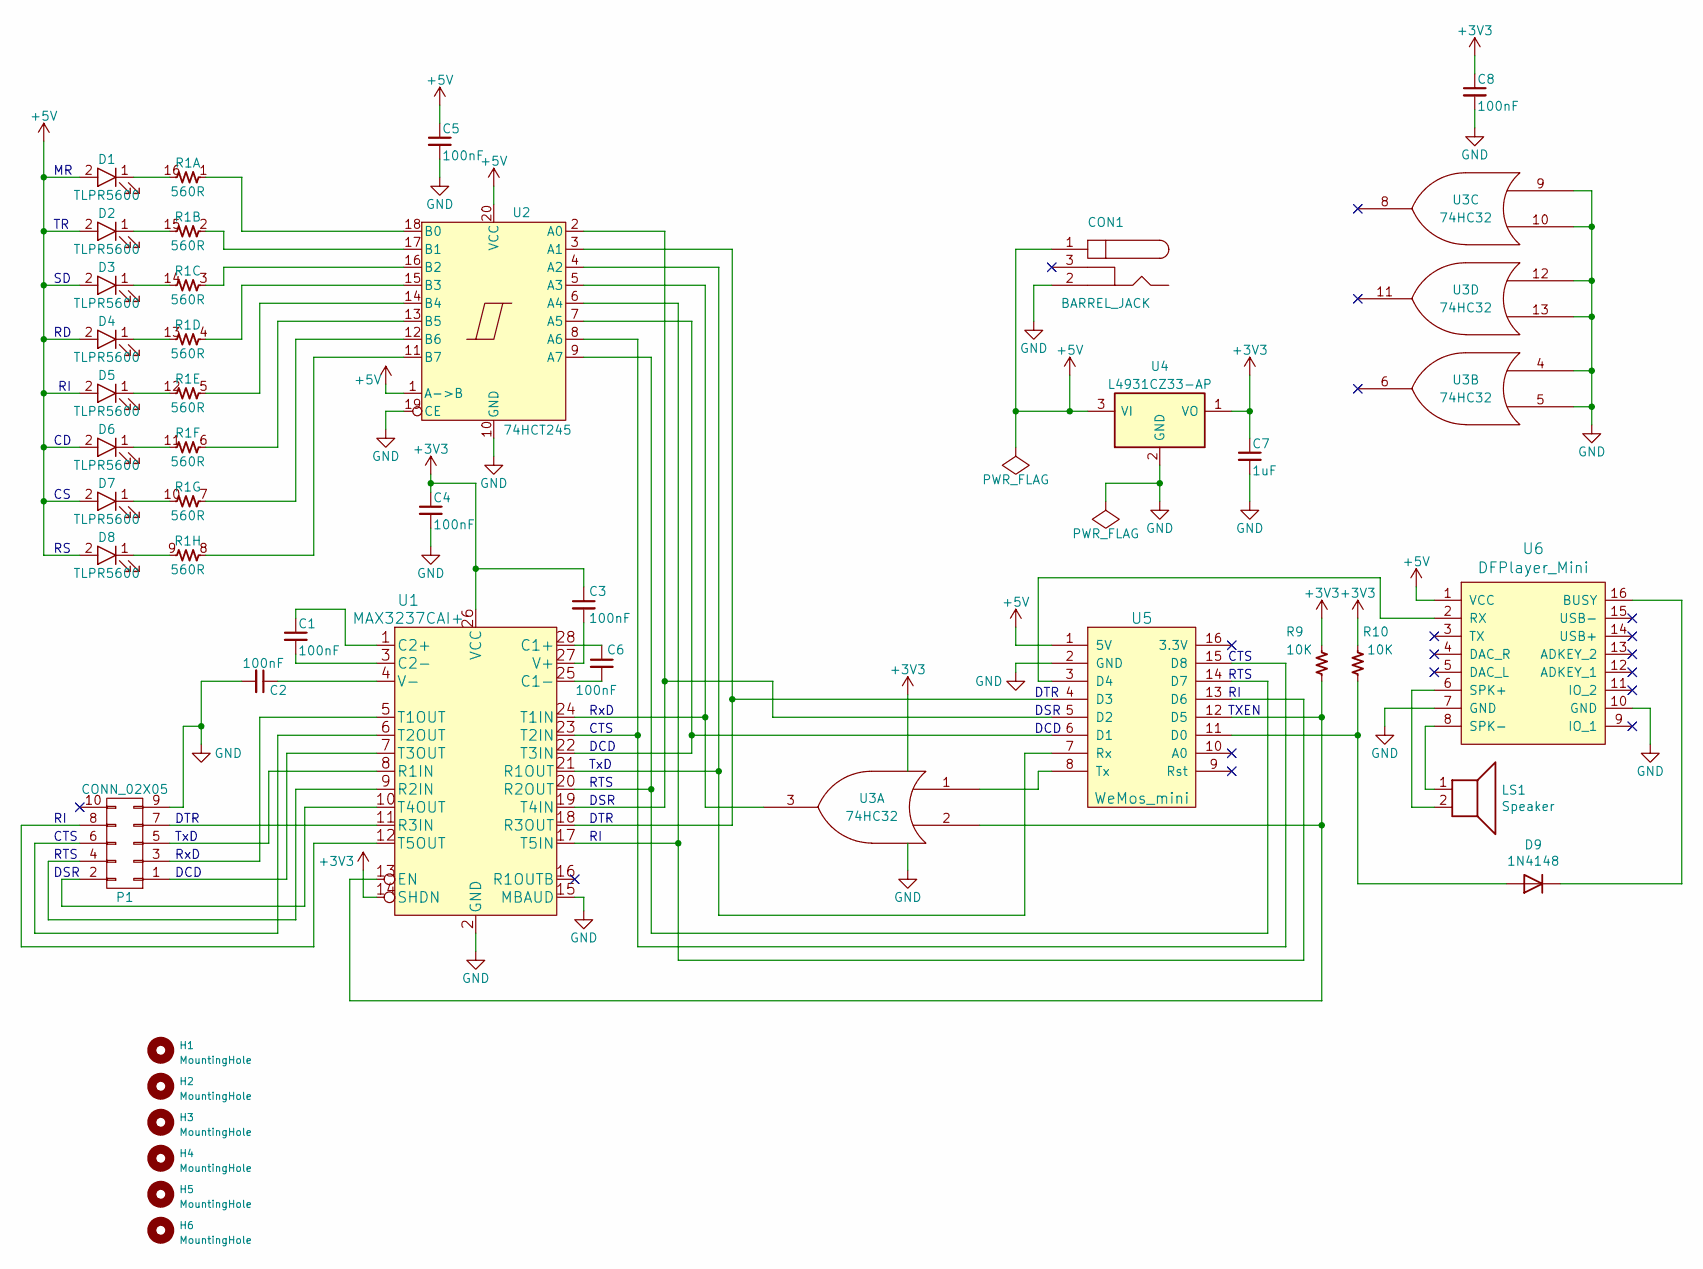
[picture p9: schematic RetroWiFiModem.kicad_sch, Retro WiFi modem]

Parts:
C1, C2, C3, C4, C5, C8: 100nF; C_Disc_D3_P2.5; DigiKey PN 399-9859-1-ND
C6: 100nF; R3; DigiKey PN 399-9843-ND
C7: 1uF; C_Disc_D3_P2.5; DigiKey PN 399-3529-ND
CON1: BARREL_JACK; BarrelJack_Horizontal; DigiKey PN 839-54-00166-ND
D1, D2, D3, D4, D5, D6, D7, D8: TLPR5600; LED-3MM; DigiKey PN TLPR5600-ND
D9: 1N4148; D_DO-35_SOD27_P7.62mm_Horizontal
H1, H2, H3, H4, H5, H6: MountingHole; MountingHole_3.2mm
LS1: Speaker; PinHeader_1x02_P2.54mm_Vertical
P1: CONN_02X05; IDC_Header_Straight_10pins; DigiKey PN ED1543-ND
R1: 560R; DIP-16_W7.62mm_LongPads; DigiKey PN CF18JT560RCT-ND
R9, R10: 10K; R3; DigiKey PN CF18JT10K0CT-ND
U1: MAX3237CAI+; SOIC-28W_7.5x17.9mm_Pitch1.27mm
U2: 74HCT245; SOIC-20W_7.5x12.8mm_P1.27mm
U3: 74HC32; SOIC-14_3.9x8.7mm_P1.27mm; DigiKey PN 296-1589-5-ND
U4: L4931CZ33-AP; TO-92_Inline_Wide; DigiKey PN LP2950ACZ-3.3GOS-ND
U5: WeMos_mini; wemos-d1-mini-with-pin-header-and-connector
U6: DFPlayer_Mini; DFPlayerMini

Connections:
+3V3: C3.1, C4.1, C7.1, C8.1, R9.1, R10.1, U1.14 (SHDN), U1.26 (VCC), U3.14 (VCC), U4.1 (VO)
+5V: C5.1, CON1.1, D1.2 (A), D2.2 (A), D3.2 (A), D4.2 (A), D5.2 (A), D6.2 (A), D7.2 (A), D8.2 (A), U2.1 (A->B), U2.20 (VCC), U4.3 (VI), U5.1 (5V), U6.1 (VCC)
GND: C2.2, C4.2, C5.2, C7.2, C8.2, CON1.2, P1.9, U1.2 (GND), U1.15 (MBAUD), U2.10 (GND), U2.19 (CE), U3.4, U3.5, U3.7 (GND), U3.9, U3.10, U3.12, U3.13, U4.2 (GND), U5.2 (GND), U6.7 (GND), U6.10 (GND)
unnamed: C1.1, U1.1 (C2+)
unnamed: C1.2, U1.3 (C2-)
unnamed: C2.1, U1.4 (V-)
unnamed: C3.2, U1.27 (V+)
unnamed: C6.1, U1.28 (C1+)
unnamed: C6.2, U1.25 (C1-)
unnamed: D1.1 (K), R1.16 (R1.2)
unnamed: D2.1 (K), R1.15 (R1.2)
unnamed: D3.1 (K), R1.14 (R1.2)
unnamed: D4.1 (K), R1.13 (R1.2)
unnamed: D5.1 (K), R1.12 (R1.2)
unnamed: D6.1 (K), R1.11 (R1.2)
unnamed: D7.1 (K), R1.10 (R1.2)
unnamed: D8.1 (K), R1.9 (R1.2)
unnamed: D9.1 (K), U6.16 (BUSY)
unnamed: D9.2 (A), R10.2, U5.11 (D0)
unnamed: LS1.1, U6.8 (SPK-)
unnamed: LS1.2, U6.6 (SPK+)
unnamed: P1.1, U1.7 (T3OUT)
unnamed: P1.2, U1.10 (T4OUT)
unnamed: P1.3, U1.5 (T1OUT)
unnamed: P1.4, U1.9 (R2IN)
unnamed: P1.5, U1.8 (R1IN)
unnamed: P1.6, U1.6 (T2OUT)
unnamed: P1.7, U1.11 (R3IN)
unnamed: P1.8, U1.12 (T5OUT)
unnamed: R1.1 (R1.1), U2.18 (B0)
unnamed: R1.2 (R1.1), U2.17 (B1)
unnamed: R1.3 (R1.1), U2.16 (B2)
unnamed: R1.4 (R1.1), U2.15 (B3)
unnamed: R1.5 (R1.1), U2.14 (B4)
unnamed: R1.6 (R1.1), U2.13 (B5)
unnamed: R1.7 (R1.1), U2.12 (B6)
unnamed: R1.8 (R1.1), U2.11 (B7)
unnamed: R9.2, U1.13 (EN), U3.2, U5.12 (D5)
unnamed: U1.17 (T5IN), U2.6 (A4), U5.13 (D6)
unnamed: U1.18 (R3OUT), U2.3 (A1), U5.4 (D3)
unnamed: U1.19 (T4IN), U2.2 (A0), U5.5 (D2)
unnamed: U1.20 (R2OUT), U2.9 (A7), U5.14 (D7)
unnamed: U1.21 (R1OUT), U2.4 (A2), U5.7 (Rx)
unnamed: U1.22 (T3IN), U2.7 (A5), U5.6 (D1)
unnamed: U1.23 (T2IN), U2.8 (A6), U5.15 (D8)
unnamed: U1.24 (T1IN), U2.5 (A3), U3.3
unnamed: U3.1, U5.8 (Tx)
unnamed: U5.3 (D4), U6.2 (RX)

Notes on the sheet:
DCD
CTS
DSR
TxD
DTR
RxD
RTS
TXEN

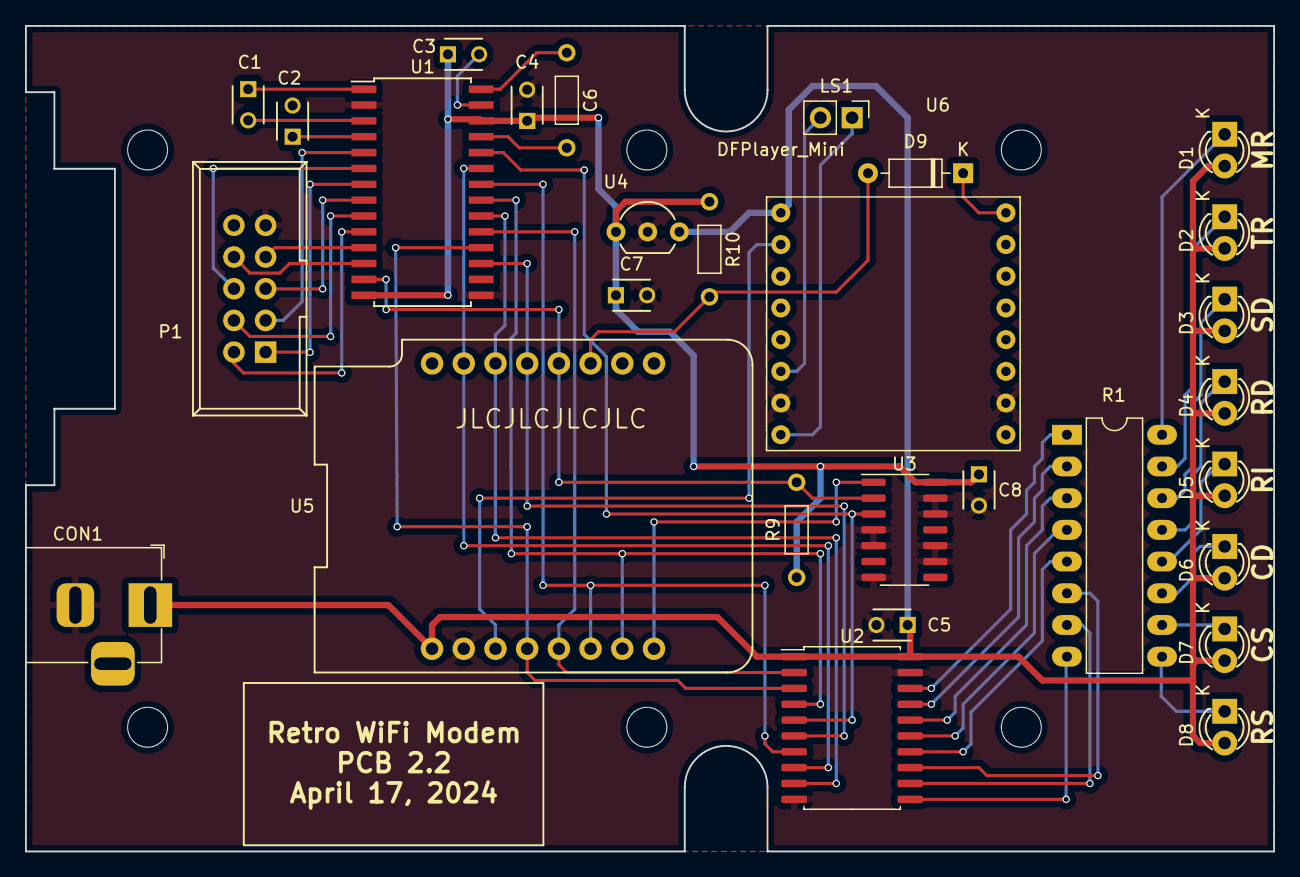
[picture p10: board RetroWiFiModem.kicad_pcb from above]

Board: 2 copper layers, 100.0 x 66.1 mm, 35 parts (0 on the bottom side), 48 nets.

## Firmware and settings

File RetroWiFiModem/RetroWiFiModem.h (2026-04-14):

#ifndef _MODEM_H
   #define _MODEM_H

   #define DEBUG                 0
   #define DEFAULT_SPEED         1200

   #define RING_INTERVAL         1500
   #define MAX_CMD_LEN           256
   #define TX_BUF_SIZE           256
   #define ESC_CHAR              '+'
   #define ESC_COUNT             3
   #define GUARD_TIME            1000
   #define MAGIC_NUMBER          0x0002
   #define MAX_SSID_LEN          32
   #define MAX_WIFI_PWD_LEN      64
   #define DEFAULT_LISTEN_PORT   6400
   #define TELNET_PORT           23
   #define HTTP_PORT             80
   #define SPEED_DIAL_SLOTS      10
   #define MAGIC_ANSWER_RINGS    3
   #define MAX_ALIAS_LEN         16
   #define MAX_SPEED_DIAL_LEN    50
   #define MAGIC_SPEED_LEN       7
   #define MAX_MDNSNAME_LEN      80
   #define MAX_BUSYMSG_LEN       80
   #define MAX_PWD_LEN           80
   #define PASSWORD_TIME         60000
   #define PASSWORD_TRIES        3
   #define MAX_AUTOEXEC_LEN      80
   #define MAX_TERMINAL_LEN      80
   #define MAX_LOCATION_LEN      80

   #define NUL  '\x00'
   #define CTLC '\x03'
   #define BS   '\x08'
   #define LF   '\x0A'
   #define CR   '\x0D'
   #define DEL  '\x7F'

   #define NO_TELNET   ((uint8_t)0)
   #define REAL_TELNET ((uint8_t)1)
   #define FAKE_TELNET ((uint8_t)2)

   // Telnet codes
   #define VLSUP     ((uint8_t)0)
   #define VLREQ     ((uint8_t)1)
   #define LOC       ((uint8_t)23)
   #define TTYPE     ((uint8_t)24)
   #define NAWS      ((uint8_t)31)
   #define TSPEED    ((uint8_t)32)
   #define LFLOW     ((uint8_t)33)
   #define LINEMODE  ((uint8_t)34)
   #define XDISPLOC  ((uint8_t)35)
   #define NEW_ENVIRON ((uint8_t)39)
   #define MSDP      ((uint8_t)69)  //
   #define MSSP      ((uint8_t)70)  //
   #define MCCP      ((uint8_t)85)  //
   #define MCCP2     ((uint8_t)86)  //
   #define MCCP3     ((uint8_t)87)  // MUD Telnet extensions
   #define MSP       ((uint8_t)91)  //
   #define MXP       ((uint8_t)93)  //
   #define GMCP      ((uint8_t)201) //
   #define BINARY    ((uint8_t)0)
   #define ECHO      ((uint8_t)1)
   #define SUP_GA    ((uint8_t)3)
   #define SE        ((uint8_t)240)
   #define DM        ((uint8_t)242)
   #define AYT       ((uint8_t)246)
   #define SB        ((uint8_t)250)
   #define WILL      ((uint8_t)251)
   #define WONT      ((uint8_t)252)
   #define DO        ((uint8_t)253)
   #define DONT      ((uint8_t)254)
   #define IAC       ((uint8_t)255)

   #define NIST_HOST "time-a-g.nist.gov"
   #define NIST_PORT 13

   #define ACTIVE LOW           // RS232 control signals are active low

   // As the ESP8266 is being used as a modem (DCE) in this application,
    // I've reversed the naming of RTS/CTS to match what they'd be on
    // a modem. The usual naming is correct if the ESP8266 is wired up as
    // a DTE, but kept confusing me here as it's wired up as a DCE.
   #ifdef ARDUINO_ESP8266_WEMOS_D1R1
      // D1 R1 pins
      #define CTS D10           // (GPIO15) output
      #define RTS D11           // (GPIO13) input
      #define RI  D12           // (GPIO12) output
      #define DSR D4            // (GPIO04) output
      #define DCD D3            // (GPIO05) output
      #define DTR D8            // (GPIO00) input
      #define TXEN D5           // (GPIO14) output
      #define BUSY D2           // (GPIO16) input
   #endif

   #ifdef ARDUINO_ESP8266_WEMOS_D1MINI
      // D1 mini pins
      #define CTS D8            // (GPIO15) output
      #define RTS D7            // (GPIO13) input
      #define RI  D6            // (GPIO12) output
      #define DSR D2            // (GPIO04) output
      #define DCD D1            // (GPIO05) output
      #define DTR D3            // (GPIO00) input
      #define TXEN D5           // (GPIO14) output
      #define BUSY D0           // (GPIO16) input
   #endif

   // Sound player definitions
   #define SOUND_DIAL_TONE 1
   #define SOUND_DIALLING (SOUND_DIAL_TONE+1)
   #define NUM_DIAL_SOUNDS 10
   #define SOUND_RING (SOUND_DIALLING+NUM_DIAL_SOUNDS)
   #define SOUND_CONNECT_300 (SOUND_RING+1)
   #define SOUND_CONNECT_1200 (SOUND_CONNECT_300+1)
   #define SOUND_CONNECT_9600 (SOUND_CONNECT_1200+1)

#endif

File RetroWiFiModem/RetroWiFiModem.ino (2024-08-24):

//
//   Retro WiFi modem: an ESP8266 based RS232<->WiFi modem
//   with Hayes style AT commands and blinking LEDs.
//
//   Originally based on
//   Original Source Copyright (C) 2016 Jussi Salin <salinjus@gmail.com>
//   Additions (C) 2018 Daniel Jameson, Stardot Contributors
//   Additions (C) 2018 Paul Rickards <rickards@gmail.com>
//
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

#include <ESP8266WiFi.h>
#include <ESP_EEPROM.h>
#include <WiFiUdp.h>
#include <ArduinoOTA.h>
#include <uart_register.h>
#include <string.h>
#include "RetroWiFiModem.h"
#include "globals.h"
#include "support.h"
#include "player.h"
#include "at_basic.h"
#include "at_extended.h"
#include "at_proprietary.h"

// =============================================================
void setup(void) {
   pinMode(RI, OUTPUT);
   pinMode(DCD, OUTPUT);
   pinMode(DSR, OUTPUT);
   digitalWrite(TXEN, HIGH);     // continue disabling TX until
   pinMode(TXEN, OUTPUT);        // we have set up the Serial port
   pinMode(DTR, INPUT);

   digitalWrite(RI, !ACTIVE);    // not ringing
   digitalWrite(DCD, !ACTIVE);   // not connected
   digitalWrite(DSR, !ACTIVE);   // modem is not ready

   EEPROM.begin(sizeof(struct Settings));
   EEPROM.get(0, settings);
   if( settings.magicNumber != MAGIC_NUMBER ) {
      // no valid data in EEPROM/NVRAM, populate with defaults
      factoryDefaults(NULL);
   }
   sessionTelnetType = settings.telnet;

   playerInit();
   playerSetVolume(settings.volume);
   if( !settings.speaker ) {
      playerMute();
   }

   Serial.begin(settings.serialSpeed, getSerialConfig());
   digitalWrite(TXEN, LOW);      // enable the TX output
   if( settings.rtsCts ) {
      setHardwareFlow();
   }
   // enable interrupt when DTR goes inactive if we're not ignoring it
   if( settings.dtrHandling != DTR_IGNORE ) {
      attachInterrupt(digitalPinToInterrupt(DTR), dtrIrq, RISING);
   }

   if( settings.startupWait ) {
      while( true ) {            // wait for a CR
         yield();
         if( Serial.available() ) {
            if( Serial.read() == CR ) {
               break;
            }
         }
      }
   }

   WiFi.begin();
   if( settings.ssid[0] ) {
      WiFi.waitForConnectResult();
      WiFi.mode(WIFI_STA);
   }
   WiFiClient::setDefaultNoDelay(true);  // disable Nalge algorithm by default

   if( settings.listenPort ) {
      tcpServer.begin(settings.listenPort);
   }

   if( settings.ssid[0] && WiFi.status() == WL_CONNECTED ) {
      setupOTAupdates();
   }

   if( WiFi.status() == WL_CONNECTED || !settings.ssid[0] ) {
      if( WiFi.status() == WL_CONNECTED ) {
         digitalWrite(DSR, ACTIVE);  // modem is finally ready or SSID not configured
      }
      if( settings.autoExecute[0] ) {
         strncpy(atCmd, settings.autoExecute, MAX_CMD_LEN);
         atCmd[MAX_CMD_LEN] = NUL;
         if( settings.echo ) {
            Serial.println(atCmd);
         }
         doAtCmds(atCmd);                  // auto execute command
      } else {
         sendResult(R_OK);
      }
   } else {
      sendResult(R_ERROR);           // SSID configured, but not connected
   }

   playerSetVolume(settings.volume);
   if( !settings.speaker ) {
      playerMute();
   }
}

// =============================================================
void loop(void) {

   checkForIncomingCall();

   if( settings.dtrHandling == DTR_RESET && checkDtrIrq() ) {
      resetToNvram(NULL);
   }

   switch( state ) {

      case CMD_NOT_IN_CALL:
         if( WiFi.status() == WL_CONNECTED ) {
            ArduinoOTA.handle();
         }
         inAtCommandMode();
         break;

      case CMD_IN_CALL:
         inAtCommandMode();
         if( state == CMD_IN_CALL && !tcpClient.connected() ) {
            endCall();                    // hang up if not in a call
         }
         break;

      case PASSWORD:
         inPasswordMode();
         break;

      case ONLINE:
         if( Serial.available() ) {       // data from RS-232 to Wifi
            sendSerialData();
         }

         while( tcpClient.available() && !Serial.available() ) { // data from WiFi to RS-232
            int c = receiveTcpData();
            if( c != -1 ) {
               Serial.write((char)c);
            }
         }

         if( escCount == ESC_COUNT && startGuardTime && millis() - startGuardTime > GUARD_TIME ) {
            state = CMD_IN_CALL;          // +++ detected, back to command mode
            sendResult(R_OK);
            escCount = 0;
         }

         if( settings.dtrHandling != DTR_IGNORE && checkDtrIrq() ) {
            switch( settings.dtrHandling ) {

               case DTR_GOTO_COMMAND:
                  state = CMD_IN_CALL;
                  sendResult(R_OK);
                  escCount = 0;
                  break;

               case DTR_END_CALL:
                  endCall();
                  break;

               case DTR_RESET:
                  resetToNvram(NULL);
                  break;

               default:
                  break;
            }
         }

         if( !tcpClient.connected() ) {   // no client?
            endCall();                    // then hang up
         }
         break;
   }
}

// =============================================================
void doAtCmds(char *atCmd) {
   size_t len;

   trim(atCmd);               // get rid of leading and trailing spaces
   if( atCmd[0] ) {
      // is it an AT command?
      if( strncasecmp(atCmd, "AT", 2) ) {
         sendResult(R_ERROR); // nope, time to die
      } else {
         // save command for possible future A/
         strncpy(lastCmd, atCmd, MAX_CMD_LEN);
         lastCmd[MAX_CMD_LEN] = NUL;
         atCmd += 2;          // skip over AT prefix
         len = strlen(atCmd);

         if( !atCmd[0] ) {
            // plain old AT
            sendResult(R_OK);
         } else {
            trim(atCmd);
            while( atCmd[0] ) {
               if( !strncasecmp(atCmd, "?", 1)  ) { // help message
                  // help
                  atCmd = showHelp(atCmd + 1);
               } else if( !strncasecmp(atCmd, "$AYT", 4) ) {
                  atCmd = doAreYouThere(atCmd + 4);
               } else if( !strncasecmp(atCmd, "$SB", 3) ) {
                  // query/set serial speed
                  atCmd = doSpeedChange(atCmd + 3);
               } else if( !strncasecmp(atCmd, "$SU", 3) ) {
                  // query/set serial data configuration
                  atCmd = doDataConfig(atCmd + 3);
               } else if( !strncasecmp(atCmd, "$SSID", 5) ) {
                  // query/set WiFi SSID
                  atCmd = doSSID(atCmd + 5);
               } else if( !strncasecmp(atCmd, "$PASS", 5) ) {
                  // query/set WiFi password
                  atCmd = doWiFiPassword(atCmd + 5);
               } else if( !strncasecmp(atCmd, "C", 1) ) {
                  // connect/disconnect to WiFi
                  atCmd = wifiConnection(atCmd + 1);
               } else if( !strncasecmp(atCmd, "D", 1) && len > 2 && strchr("TPI", toupper(atCmd[1])) ) {
                  // dial a number
                  atCmd = dialNumber(atCmd + 2);
               } else if( !strncasecmp(atCmd, "DS", 2) && len == 3 ) {
                  // speed dial a number
                  atCmd = speedDialNumber(atCmd + 2);
               } else if( !strncasecmp(atCmd, "H0", 2) ) {
                  // hang up call
                  atCmd = hangup(atCmd + 2);
               } else if( !strncasecmp(atCmd, "H", 1) && !isDigit(atCmd[1]) ) {
                  // hang up call
                  atCmd = hangup(atCmd + 1);
               } else if( !strncasecmp(atCmd, "&Z", 2) && isDigit(atCmd[2]) ) {
                  // speed dial query or set
                  atCmd = doSpeedDialSlot(atCmd + 2);
               } else if( !strncasecmp(atCmd, "L", 1) ) {
                  // query/set speaker volume
                  atCmd = doSpeakerVolume(atCmd + 1);
               } else if( !strncasecmp(atCmd, "M", 1) ) {
                  // turn speaker on/off
                  atCmd = doSpeaker(atCmd + 1);
               } else if( !strncasecmp(atCmd, "O", 1) ) {
                  // go online
                  atCmd = goOnline(atCmd + 1);
               } else if( !strncasecmp(atCmd, "GET", 3) ) {
                  // get a web page (http only, no https)
                  atCmd = httpGet(atCmd + 3);
               } else if( settings.listenPort && !strncasecmp(atCmd, "A", 1) && tcpServer.hasClient() ) {
                  // manually answer incoming connection
                  atCmd = answerCall(atCmd + 1);
               } else if( !strncasecmp(atCmd, "S0", 2) ) {
                  // query/set auto answer
                  atCmd = doAutoAnswerConfig(atCmd + 2);
               } else if( !strncasecmp(atCmd, "S2", 2) ) {
                  // query/set escape character
                  atCmd = doEscapeCharConfig(atCmd + 2);
               } else if( !strncasecmp(atCmd, "$SP", 3) ) {
                  // query set inbound TCP port
                  atCmd = doServerPort(atCmd + 3);
               } else if( !strncasecmp(atCmd, "$BM", 3) ) {
                  // query/set busy message
                  atCmd = doBusyMessage(atCmd + 3);
               } else if( !strncasecmp(atCmd, "&R", 2) ) {
                  // query/set require password
                  atCmd = doServerPassword(atCmd + 2);
               } else if( !strncasecmp(atCmd, "I", 1) ) {
                  // show network information
                  atCmd = showNetworkInfo(atCmd + 1);
               } else if( !strncasecmp(atCmd, "Z", 1) ) {
                  // reset to NVRAM
                  atCmd = resetToNvram(atCmd + 1);
               } else if( !strncasecmp(atCmd, "&D", 2) ) {
                  //query/set DTR handling
                  atCmd = doDtrHandling(atCmd + 2);
               } else if( !strncasecmp(atCmd, "&V", 2) ) {
                  // display current and stored settings
                  atCmd = displayAllSettings(atCmd + 2);
               } else if( !strncasecmp(atCmd, "&W", 2) ) {
                  // write settings to EEPROM
                  atCmd = updateNvram(atCmd + 2);
               } else if( !strncasecmp(atCmd, "&F", 2) ) {
                  // factory defaults
                  atCmd = factoryDefaults(atCmd);
               } else if( !strncasecmp(atCmd, "E", 1) ) {
                  // query/set command mode echo
                  atCmd = doEcho(atCmd + 1);
               } else if( !strncasecmp(atCmd, "Q", 1) ) {
                  // query/set quiet mode
                  atCmd = doQuiet(atCmd + 1);
               } else if( !strncasecmp(atCmd, "RD", 2)
                       || !strncasecmp(atCmd, "RT", 2) ) {
                  // read time and date
                  atCmd = doDateTime(atCmd + 2);
               } else if( !strncasecmp(atCmd, "V", 1) ) {
                  // query/set verbose mode
                  atCmd = doVerbose(atCmd + 1);
               } else if( !strncasecmp(atCmd, "X", 1) ) {
                  // query/set extended result codes
                  atCmd = doExtended(atCmd + 1);
               } else if( !strncasecmp(atCmd, "$W", 2) ) {
                  // query/set startup wait
                  atCmd = doStartupWait(atCmd + 2);
               } else if( !strncasecmp(atCmd, "NET", 3) ) {
                  // query/set telnet mode
                  atCmd = doTelnetMode(atCmd + 3);
               } else if( !strncasecmp(atCmd, "$AE", 3) ) {
                  // do auto execute commands
                  atCmd = doAutoExecute(atCmd + 3);
               } else if( !strncasecmp(atCmd, "$TTY", 4) ) {
                  // do telnet terminal type
                  atCmd = doTerminalType(atCmd + 4);
               } else if( !strncasecmp(atCmd, "$TTL", 4) ) {
                  // do telnet location
                  atCmd = doLocation(atCmd + 4);
               } else if( !strncasecmp(atCmd, "$TTS", 4) ) {
                  // do telnet location
                  atCmd = doWindowSize(atCmd + 4);
               } else if( !strncasecmp(atCmd, "&K", 2) ) {
                  // do RTS/CTS flow control
                  atCmd = doFlowControl(atCmd + 2);
               } else if( !strncasecmp(atCmd, "$MDNS", 5) ) {
                  // handle mDNS name
                  atCmd = doMdnsName(atCmd + 5);
               } else {
                  // unrecognized command
                  sendResult(R_ERROR);
               }
               trim(atCmd);
            }
         }
      }
   }
}

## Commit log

2020-04-28 Added a section on my modification to the uart.cpp file in the ESP8266 core to keep the watchdog fed and happy during long waits for space in the serial transmit FIFO.
2020-07-19 Auto switch telnet mode option on session basis. ATDTnumber will use the currently defined telnet mode. ATDT+number will use NET2 for the session and return to the defined telnet mode when the sessio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
2020-08-24 Added a picture of the original prototype to the readme file.
2020-09-29 update symbols and footprints for KiCad 5.1.2
    * remaps all symbols and footprints to those present in KiCad 5.1.2.
    * add mounting holes to schematics
    * PCB has been touched up due to footprint changes, but should remain
    almost identical to the original
    * NOTE: schematic now has some warnings about tristate<->output connections
    symbols and footprints are mapped as follows:
    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
    [RetroWiFiModem.kicad_pcb, RetroWiFiModem.sch]
2020-10-02 Renamed KiCad4 files as "-kicad4" for upcoming pull.
    [RetroWiFiModem-kicad4-bom.csv, RetroWiFiModem-kicad4.kicad_pcb, RetroWiFiModem-kicad4.sch]
2020-10-02 Revert "Renamed KiCad4 files as "-kicad4" for upcoming pull."
    This reverts commit bb5cc11a9b487fb4e979007bafb8acc164f68607.
    [RetroWiFiModem-kicad4-bom.csv, RetroWiFiModem-kicad4.kicad_pcb, RetroWiFiModem-kicad4.sch]
2020-10-02 Trying to re-can a can of worms...
    [RetroWiFiModem-bom.csv, RetroWiFiModem.kicad_pcb, RetroWiFiModem.sch]
2020-10-05 Race condition with '+++' and remote ending connection fixed. Timing is everything: discovered that if I typed the escape sequence +++ and the remote end dropped the connection within the 1 second gu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
    [support.h]
2020-11-25 Command buffer needs to be emptied on error in quiet mode In non-quiet, when an ERROR is returned, the command buffer was emptied. In quiet, nothing would happen, the code would go into an infinite l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
    [support.h]
2020-11-26 Tracked down a bug with ASCII text at higher baud rates There's been a long standing problem with sending ASCII text (serial -> WiFi) in file transfers. Above 4.8K, it just wouldn't hardly ever work.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
    There's more testing to be done but I've already done
    batch Ymodem sends at 38.4K and that's the first time
    I'm had those working that fast.
    [support.h]
2021-04-21 Added paging to the help (AT?) and network status (ATI) commands. I have an old SSM VB1 video board (64 columns by 16 rows) and decided to add output paging so that the text wouldn't scroll off the s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
2021-12-21 Removed a couple of duplicated items in the help text.
2022-09-20 Fixed a spelling mistake.
    [at_basic.h]
2022-09-29 Added code to request character mode on manual (ATA) answer. As a learning exercise, I've been porting the code to a Raspberry Pi Pico W. Aside from the earlier spelling mistake, this is the first "o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
    [at_basic.h]
2022-10-01 Added Hayes-style S2 (online escape sequence character) support. Discovered during more Pico W wifi modem testing that when connected to another wifi modem, a +++ sequence would put both ends in comm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
2022-10-02 Endless loop of Telnet commands when 2 modems connected together. Another "found it while debugging the Pico W" code bug. A wifi modem dialled into another wifi modem would result in an endless loop 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
    [at_basic.h, support.h]
2022-10-11 Tightened up inter char spacing in online escape sequence.
    [support.h]
2022-10-17 Fixed a "been there forever" bug in ATH. Not fatal, but annoying.
    [RetroWiFiModem.ino, at_basic.h, support.h]
2023-03-15 Initial commit for the v2 hardware. * MAX3237 for full suite of RS-232 control signals * DFPlayer Mini for faux dialing and connection sounds * Gerbers suitable for JLCPCB included
    [RetroWiFiModem-B_Cu.gbl, RetroWiFiModem-B_Mask.gbs, RetroWiFiModem-B_Paste.gbp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]
2023-03-15 Cleaning up old files
    [RetroWiFiModem-kicad4-bom.csv, RetroWiFiModem-kicad4.kicad_pcb, RetroWiFiModem-kicad4.sch]
2023-03-22 Increased the intermediate volume levels (ATL1 & ATL2) to be better heard through the case.
2023-06-10 Added note on price increase on red LED panel
2024-08-14 Updated to KiCad 6.0
    [RetroWiFiModem.kicad_sch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]
2024-08-14 Completed KiCad 6.0 updates
    [RetroWiFiModem-B_Cu.gbl, RetroWiFiModem-B_Mask.gbs, RetroWiFiModem-B_Paste.gbp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]
2024-08-14 Recompiled with all warnings enabled; pruned out some dead code and fixed a few "that's mostly harmless but not right" bits.
    [RetroWiFiModem.ino, at_basic.h, support.h]
2024-08-24 Modified a handful of instances using millis for delays where there was the minute possibility of wrap around. Also increased the delay between the end of the dialing DTMF tones and the first ring.
2024-08-24 Added current .bin file
2026-04-14 DTR transition wasn't being cleared on answering an incoming call. First bug in 2 years. I hooked a modem up to a system with all the control lines and enabled DTR dropping to end a call. The system 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
    Also, time.nist.gov has been having issues all year, so I've
    routed to a specific NIST host.
    [RetroWiFiModem.h, support.h]

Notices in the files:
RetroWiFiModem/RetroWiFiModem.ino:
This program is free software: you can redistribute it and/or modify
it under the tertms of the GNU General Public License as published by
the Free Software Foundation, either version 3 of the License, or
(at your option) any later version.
